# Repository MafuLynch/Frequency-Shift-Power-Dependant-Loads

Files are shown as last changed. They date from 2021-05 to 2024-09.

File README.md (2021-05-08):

# Frequency-Shift-Power-Dependant-Loads
Arduino based load control that depends on frequency for off-grid AC coupled systems. As batteries get charged, solar or wind generation needed will decreasse, lowering the PV output or activating dump load of wind turbine. With this controller, you will be able to activate AC loads automatically so that power generation is not reduced. First prototype will increment power linearly starting at 50,5Hz and delivering full power at 51Hz through phase control

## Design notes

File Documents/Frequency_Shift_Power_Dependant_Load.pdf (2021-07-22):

# Frequency Shift Power Dependant Load

John Matthew Lynch

July 22, 2021
V1.0

## 1 Introduction

This document is aimed at people with an off-grid AC coupled micro grid that use Frequency Shifting Power Control for power generation regulating. The objective is to design and build a controller that will optimise the use of excess renewable power that is currently not being used due to batteries being full or not able to accept as much power. Our controller will detect an increase in the grid frequency and activate a load, being able to assign 0% to 100% power if the load is a restive load. In the future a model for using other types of loads, like pumping water, will be developed. In this document the controller will be designed for a grid formed by SMA Sunny Island inverter and Fronius Primo grid-tie PV inverters. Other inverters might operate at different frequency range or use another methodology other than Frequency Shift Power Control to regulate generation, check with your inverter manufacturer.

## Glossary

P V | Photovoltaic
F SP C | Frequency Shift Power Control
P AC | Phase angle control
GT I | Grid Tie Inverter
BBI | Battery based inverter

## 2 Theory

### 2.1 Frequency Shifting Power Control

In this type of grid, our inverter is the brain of the system and will regulate where power comes and goes to. On the DC side we have the batteries and optionally a DC charger. To these batteries we have connected our battery based inverter (from now on BBI) which will generate our AC grid. On the AC side we have our loads and also the grid-tie inverter for our renewable energy (for simplicity we are going to assume we have solar energy and this is a PV inverter) all in parallel. So once batteries are full and there is less consumption than available PV energy, how do we inform our PV inverter to start reducing its output power?
The answer to this is Frequency Shifting Power Control. The PV inverters will ineject directly to our grid, all power that is needed at the moment will be consumed directly and any excess is going to be used by the BBI to charge the batteries. One the batteries are fully charged or can’t accept all the excess power in the grid, the BBI will slowly start to increase the AC frequency to indicate to the PV inverters that they should reduce their output power. For SMA inverters power reduction will start at 51Hz and will be reduced linearly to 0% at 52Hz. This can be seen by the blue line in figure 1.

1

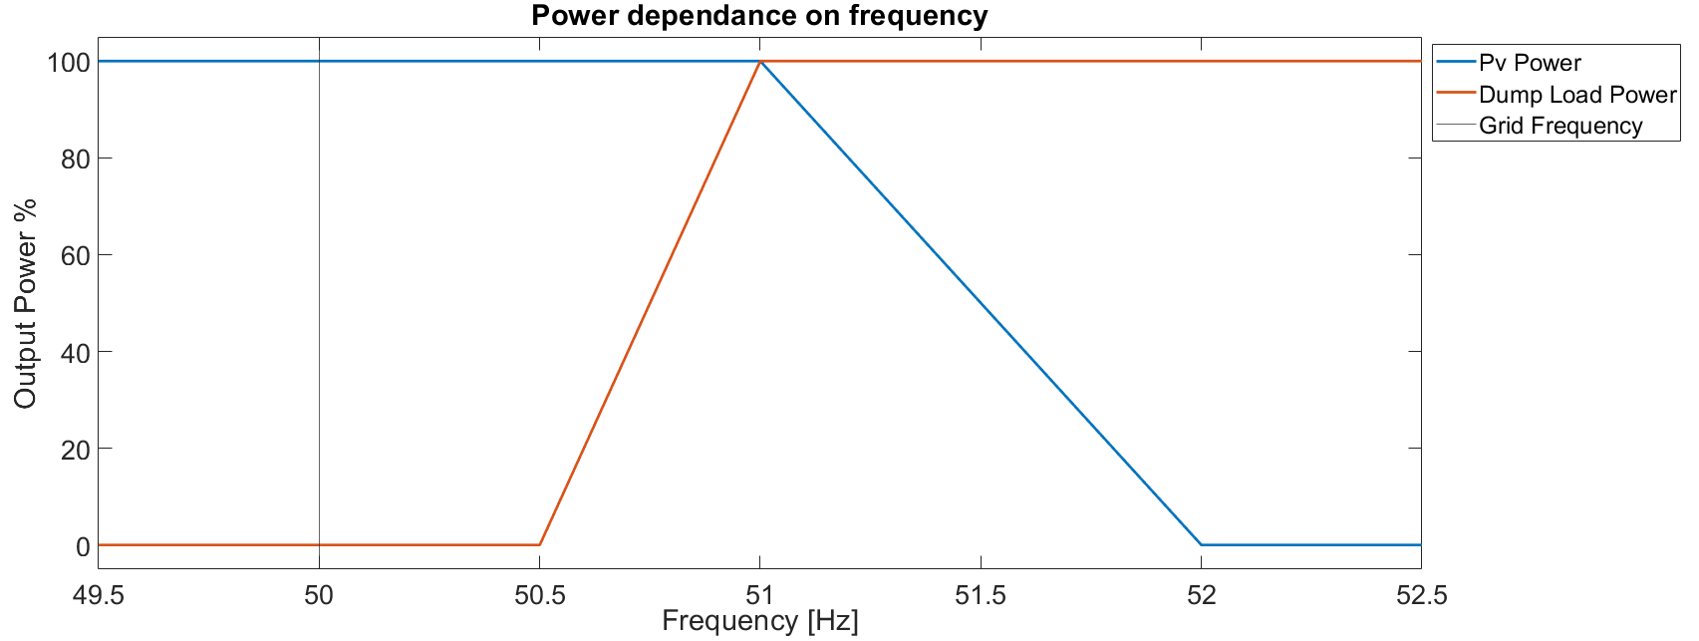
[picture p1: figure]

Figure 1: Change in power generation and load consumption based on grid frequency

So in order to maximise PV generation we want to turn on a load that will consume this excess energy so generation is maximised. This energy can be used to heat water or heat a room. So this same increase in frequency should indicate to our controller that it should star to turn on our load. Be aware that after 51Hz the PV output starts to be reduced, so our load should start to turn on before and this way PV output will only be reduced once our load is on at 100% and we still have excess generation. Another factor to take into consideration is that if we just turn our load fully on all of a sudden, this change in consumption will make our frequency drop, in effect making our load turn off again. For this reason we approach this problem using a triac to be able to perform phase angle control (from now on PAC) and be able to turn on our resistive load at any power between 0% and 100%. This way as frequency starts to go up and our load slowly turns on, it will reach equilibrium and only use the available extra power. The output power of our controller for the dump load can also be observed in figure 1 as the red line. For loads that have to be on or off, a different approach will be needed.
Be aware that these mentioned values are for SMA inverters, inverters from other brands such as Victron use different ranges and you should check in the user manual or with the manufacturer for proper configuration. Also the grid we are operating is a 50Hz grid, but this could be different depending on what country you are in.

### 2.2 Phase Angle Control

Phase angle control is a PWM approximation for AC current. It is achieved by a Triac, which job is to allow current to go through it when it receives an activation signal to its gate. Triac will stay in the on state till the current going through it reaches a minimum threshold value. So selecting the delay for the firing of the triac will allow us to choose how much time the triac is going to be in a conductive state and therefore regulate the power. As an example, for a 50Hz grid, a half wave is 10ms long. So if we have a delay of 5ms from the zero crossing point (when voltage is 0) we would effectively only use half of the sine wave and power would be 50% of that it would be in regular conditions. If the trigger signal is given to triac at the zero crossing point then output power will be 100%. This can be observed in figures 2 and 3 where with the blue line we can observe the signal our microcontroller gets to indicate the zero crossing point and in yellow we have our controller output for the load.

2

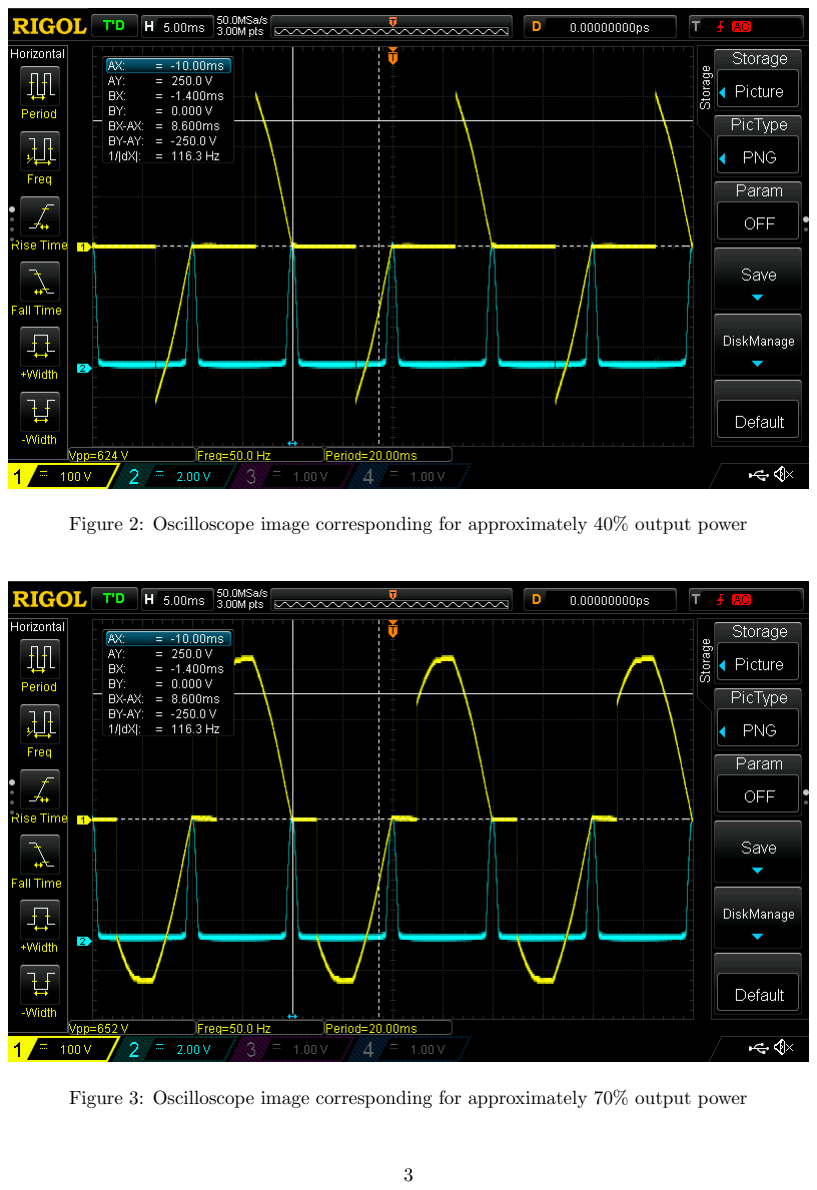
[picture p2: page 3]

Figure 2: Oscilloscope image corresponding for approximately 40% output power

Figure 3: Oscilloscope image corresponding for approximately 70% output power

3

### 2.3 The controller

Our controller will be based on a arduino nano microcontroller. This will be the brain of the controller, will measure the grid frequency and output the trigger signal for the triac.
For the project we are going to need the following components
- 1 Arduino Nano
- 1 BTA 16-600b Triac
- 1 330 Ω resistor
- 2 1kΩ resistor
- 1 10kΩ resistor
- 1 mb10f full bridge rectifier or 4 1n4007 diodes
- 1 PC817 optocoupler
- 1 MOC 3020 optocoupler for triac
- 2 3 pole block terminal
- 1 3 pin fan header
- 12V power supply
- PCB

4

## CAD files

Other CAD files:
CAD_Case_V1/Case_V1.CATPart
CAD_Case_V1/Lid_V1.CATPart

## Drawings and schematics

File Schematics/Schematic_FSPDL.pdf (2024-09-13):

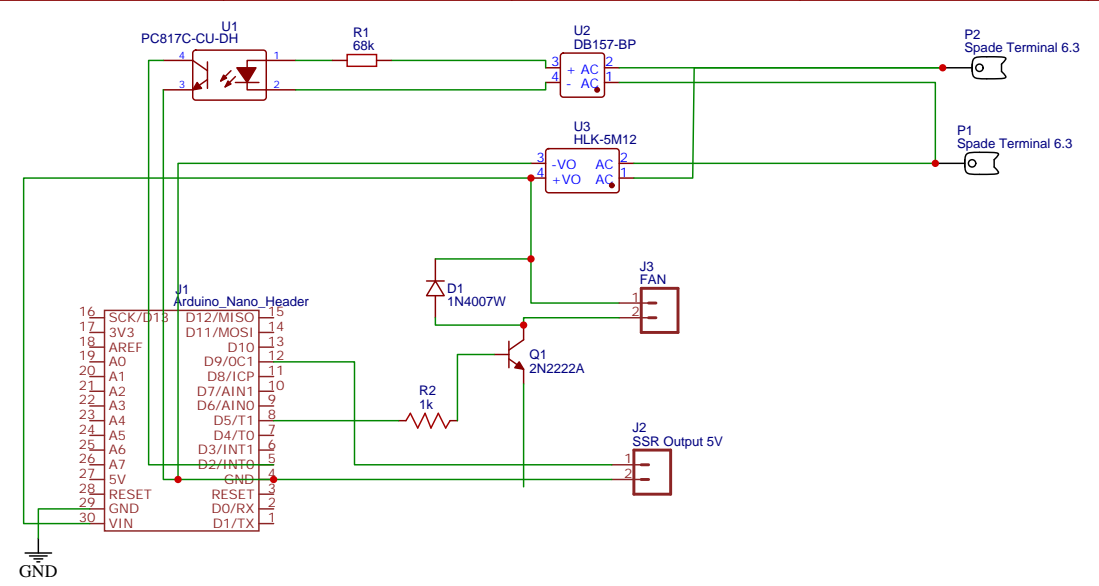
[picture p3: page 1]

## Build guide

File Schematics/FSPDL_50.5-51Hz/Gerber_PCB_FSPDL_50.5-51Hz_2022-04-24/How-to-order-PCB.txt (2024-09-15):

How to Order PCB

Please refer to:
https://docs.easyeda.com/en/PCB/Order-PCB

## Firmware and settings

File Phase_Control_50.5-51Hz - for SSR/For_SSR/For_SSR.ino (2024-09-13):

#define FAN_PIN 5
#define TEMP_SENS A0

unsigned int outputvalue;
volatile unsigned int previous = 0;
volatile uint16_t tmr1 = 0;
float period, frequency;

void setup() { 
  pinMode(9, OUTPUT);                               // Set digital pin 9 (D9) to an output
  TCCR1A = _BV(COM1A1) | _BV(WGM11);                // Enable the PWM output OC1A on digital pins 9
  TCCR1B = _BV(WGM13) | _BV(WGM12) | _BV(CS12);     // Set fast PWM and prescaler of 256 on timer 1
  ICR1 = 62499;                                     // Set the PWM frequency to 1Hz: 16MHz/(256 * 1Hz) - 1 = 62499
  OCR1A = 6249;                                     // Set the duty-cycle to 10%: 62499 / 10 = 6249
  TCNT1  = 0;   // Set Timer1 preload value to 0 (reset)
  TIMSK1 = 1;   // enable Timer1 overflow interrupt

  EIFR |= 1;  // clear INT0 flag
  
  pinMode(FAN_PIN,OUTPUT);                  // Set fan output pin
  digitalWrite(FAN_PIN,LOW);                // By default start off
  pinMode(2,INPUT_PULLUP);                  // Use internal pullup instead of external 10k ohm resistor
  attachInterrupt(0, timer1_get, FALLING);  // enable external interrupt (INT0)

  //Serial.begin(9600);
}


 
void timer1_get() {
  //tmr1 = TCNT1 - previous;
  //previous = TCNT1;
  tmr1 = TCNT1;
  TCNT1  = 0;   // reset Timer1
  
}
 
ISR(TIMER1_OVF_vect) {  // Timer1 interrupt service routine (ISR)
  tmr1 = 0;
  previous = 0;
}

void loop(){
  
  // save current Timer1 value
  uint16_t value = tmr1;
  // calculate signal frequency which is = 1/period ; or = MCU_CLK/(Prescaler * Timer_Value)
  // since using full bridge rectifier we measure half period, so f=1/2*p
  if(value == 0)
    frequency = 0;   // aviod division by zero
  else
    frequency = 16000000.0/(2*(256UL*value));

  if (frequency>50.49 && frequency<51){
    outputvalue= 2*62499*(frequency-50.5);
  }
  if (frequency>51){
    outputvalue=62499;
  }
  if (frequency<50.5){
    outputvalue=0;
  }
  OCR1A = outputvalue;

  //Serial.println(frequency);

}

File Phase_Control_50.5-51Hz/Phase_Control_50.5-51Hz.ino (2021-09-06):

int triacPin=3;
float Fdelay;
int Tdelay;
 
void setup(void) {

  pinMode(4,OUTPUT);
  digitalWrite(4,LOW);
  pinMode(12,OUTPUT);
  digitalWrite(12,LOW);

  
 
  // Timer1 module configuration
  TCCR1A = 0;
  TCCR1B = 2;   // enable Timer1 module with 1/8 prescaler ( 2 ticks every 1 us)
  TCNT1  = 0;   // Set Timer1 preload value to 0 (reset)
  TIMSK1 = 1;   // enable Timer1 overflow interrupt
 
  EIFR |= 1;  // clear INT0 flag
  attachInterrupt(0, timer1_get, FALLING);  // enable external interrupt (INT0)
}
 
uint16_t tmr1 = 0;
float period, frequency;
 
void timer1_get() {
  tmr1 = TCNT1;
  TCNT1  = 0;   // reset Timer1
    if (frequency>=50.50 && frequency <51){
      Fdelay=9200*(1+(50.5-frequency)*2);  //linear interpolation for delay
      Tdelay=int(Fdelay);
      delayMicroseconds(Tdelay);
      digitalWrite(4,HIGH);
      delayMicroseconds(50);   //revisar que es posible que este delay de 100uS este activando el triac en la siguiente onda a partir de t'=0. Tdelay + delay de codigo + delay 100uS = 9800+100+algo muy chico --> 9900uS + extra y la media onda en 50.5 son 9.9miliseg
      digitalWrite(4,LOW);

      }

}
 
ISR(TIMER1_OVF_vect) {  // Timer1 interrupt service routine (ISR)
  tmr1 = 0;
}
 

void loop() {
 
  // save current Timer1 value
  uint16_t value = tmr1;
  // calculate signal frequency which is = 1/period ; or = MCU_CLK/(Prescaler * Timer_Value)
  if(value == 0)
    frequency = 0;   // aviod division by zero
  else
    frequency = 16000000.0/(2*(8UL*value));

  if (frequency>=51.0){ //if frequency over 51Hz triac should be always on
    digitalWrite(4,HIGH);
  }

  if (frequency<50.5){ //If low frequency, deactivate triac
    digitalWrite(4,LOW);
    digitalWrite(12,LOW);
  }

  if (frequency>50.60){ //Start fan when 20% output power
    digitalWrite(12,HIGH);
    }
 
}
 

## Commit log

2021-05-08 Adding code for first phase control prototype
2021-07-04 Add CAD Case_V1
    [Case_V1.CATPart]
2021-07-04 CAD for lid has been added. Also fan control has been added to code, fan will start at when output power is 30% to avoid overheating triac. This is final edition of code Version 1. Test potentiometer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
    [Lid_V1.CATPart]
2021-07-04 CAD for lid has been added. Also fan control has been added to code, fan will start at when output power is 20% to avoid overheating triac. This is final edition of code Version 1. Test potentiometer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
    [Phase_Control_50.5-51Hz.ino]
2021-07-05 Added comments and initial delay reduced from 9300 microsecods to 9200 microsecods
    [Case_V1.CATPart]
2021-09-06 fixes after first prototype test
    [Phase_Control_50.5-51Hz.ino]
2021-09-08 Added new SSR version with 1Hz PWM signal. V0.9
2024-09-13 add fan
2024-09-13 add schematics
2024-09-15 add schematics easyeda
    [Gerber_BoardOutline.GKO, Gerber_BottomLayer.GBL, Gerber_BottomSolderMaskLayer.GBS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]
